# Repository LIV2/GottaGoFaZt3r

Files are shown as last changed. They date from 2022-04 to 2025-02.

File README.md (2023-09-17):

# GottaGoFaZt3r Fast RAM

256MB Autoconfig Fast RAM for the Amiga 3000/4000 

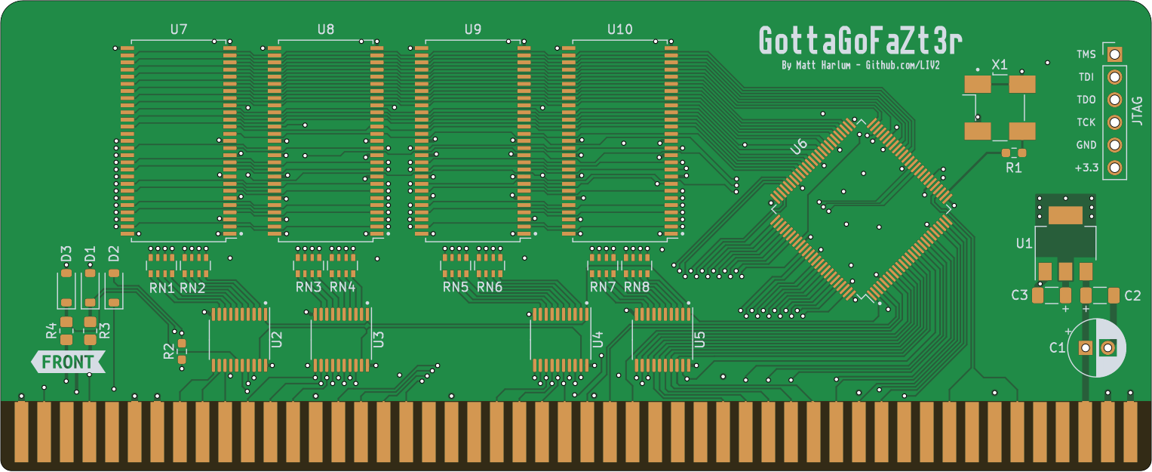
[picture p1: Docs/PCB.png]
PCB


## Table of contents
1. [Status](#status)
2. [Features](#features)
3. [Ordering PCBs](#ordering-pcbs)
4. [Bill of materials](#bill-of-materials)
5. [Troubleshooting](#troubleshooting)
6. [Special Thanks and Shoutouts](#special-thanks-and-shoutouts)
7. [License](#license)

## Status
Tested and working in the following configurations:
* Amiga 3000
* Amiga 4000 with A3640

## Features
128MB or 256MB Z3 Fast RAM  
Brand new 32Mx16 SDRAM chips are quite expensive so the board can also be fitted with 16Mx16 chips for a much lower build cost  

## Ordering PCBs
I recommend ordering from JLCPCB as this board was designed within their 4-layer specifications  
Recommended options when ordering:
* Thickness: 1.6mm
* Surface Finish: ENIG-RoHS
* Gold Fingers: Yes
* 45°finger chamfered: Yes

Layer sequence:
|Layer|File|
|-|-|
|L1|GottaGoFaSDZ3-F_Cu.gbr|
|L2|GottaGoFaSDZ3-In1_Cu.gbr|
|L3|GottaGoFaSDZ3-In2_Cu.gbr|
|L4|GottaGoFaSDZ3-B_Cu.gbr|

## Bill of materials

|Component|Location|QTY|Link|Notes|
|---|---|---|----|-----|
|0.1uF Ceramic Capacitor, 0603|C4-15,C17-44|40|[Mouser](https://www.mouser.com/ProductDetail/80-C603C104K5RAC3121)<br />[DigiKey](https://www.digikey.com/short/f7trtfwt)||
|10uF Ceramic Capacitor, 1206|C2-3,C16|3|[Mouser](https://www.mouser.com/ProductDetail/187-CL31A106MAHNNNE)<br />[DigiKey](https://www.digikey.com/short/rqt1br0q)||
|33 Ohm Resistor, 0603|R1|1|[Mouser](https://www.mouser.com/ProductDetail/603-RT0603DRE0733RL)<br />[DigiKey](https://www.digikey.com/short/40rdd4m1)||
|33 Ohm Resistor network, Convex 1206 (3.2x1.6mm)|RN1-8|8|[Mouser](https://www.mouser.com/ProductDetail/667-EXB-38V330JV)<br />[DigiKey](https://www.digikey.com/short/t08zh4pn)||
|10K Resistor, 0603|R2|1|[Mouser](https://www.mouser.com/ProductDetail/603-RT0603FRD0710KL)<br />[DigiKey](https://www.digikey.com/short/nvvrt5dw)||
|LM1117-3.3 SOT-223|U1|1|[Mouser](https://www.mouser.com/ProductDetail/926-LM1117IMP3.3NOPB)<br />[Digikey](https://www.digikey.se/short/jprv7r4q)||
|74LVC245N TSSOP|U2-5|4|[Mouser](https://www.mouser.com/ProductDetail/595-SN74LVC245APWT)<br />[DigiKey](https://www.digikey.se/short/vbmphn44)|Can be substituted with SN74LVTH245 or SN74LVCR2245|
|AS4C32M16SC 32Mx16 SDRAM, TSSOP-54|U7-10|4|[Mouser](https://www.mouser.com/ProductDetail/913-AS4C32M16SC-7TIN)<br />[DigiKey](https://www.digikey.com/short/wfwn8nmw)|Cheaper option is to use [A3V56S40GTP](https://www.mouser.com/ProductDetail/155-A3V56S40GTP-60) 16Mx16 for a 128MB configuration at a drastically lower price, or scavenge some 32Mx16 SDRAM from old SODIMMs*|
|Xilinx XC95144XL-10TQG100C 10ns 144 Macrocell CPLD|U6|1|[Mouser](https://www.mouser.com/ProductDetail/217-95144XL-10TQ100C)<br />[Digkey](https://www.digikey.com/short/w0r0j288)||
|Clock Oscillator, HCMOS, 7x5mm, 3.3V, ~66MHz|X1|1|[Mouser](https://www.mouser.com/ProductDetail/959-SM7745HEV-66.667)<br />[DigiKey](https://www.digikey.com/short/q8bzfwj4)|Anything close to 66MHz should work<br />Tested at 66.6666MHz|

__*__ I cannot provide technical support for RAM chips other than those explicitly listed in the BOM, others may work but you're on your own

## Troubleshooting
__Problem:__ The board is detected but there is less memory detected than there should be. or you see a message stating that the board is "Defective"  
__Resolution:__
1. Check all soldering looking for bad connections and shorts around the RAM and CPLD
2. Test the RAM using [ATK](https://github.com/keirf/amiga-stuff/releases)  
Look for the relevant region under "List and test regions" and test it  
Consult the memory layout to determine which IC is responsible for any stuck bits you might see

### Memory Layout
The memory is laid out in a way that causes it to wrap around above 128MB when only 128MB of ram is fitted to the card allowing either 128/256MB configuration with the same CPLD firmware.  
Kickstart will notice this wrap and add only 128MB to the free pool in this instance.

|Address|D0-15|D16-31|
|---|-----|---|
|40000000-43FFFFFF|U9|U7|
|44000000-47FFFFFF|U10|U8|
|48000000-4BFFFFFF|U9|U7|
|4C000000-4FFFFFFF|U10|U8|

## Special Thanks and Shoutouts
* [Niklas Ekström](https://github.com/niklasekstrom) for helping to clean up my messy code
* [GadgetUK164](https://www.youtube.com/gadgetuk164) for ~~being a guinea pig~~ beta testing many of my boards
* SparxUK also for being a helpful beta tester of many of my boards
* [CDH](https://github.com/cdhooper) and [Stefan Reinauer](https://github.com/reinauer) for helping me to get my A3000 going 
* [Rob "peepo" Taylor](https://tindie.com/stores/bobsbits/) whose A500++ got me started on my journey of tinkering with Amigas
* [jbilander](https://github.com/jbilander) who came up with the cool name :)
* RetroFletch
* [SukkoPera](https://github.com/SukkoPera)

## License

[][cc-by-sa]

This work is licensed under a
[Creative Commons Attribution-ShareAlike 4.0 International License][cc-by-sa].

[][cc-by-sa]

[cc-by-sa]: http://creativecommons.org/licenses/by-sa/4.0/
[cc-by-sa-image]: https://licensebuttons.net/l/by-sa/4.0/88x31.png
[cc-by-sa-shield]: https://img.shields.io/badge/License-CC%20BY--SA%204.0-lightgrey.svg

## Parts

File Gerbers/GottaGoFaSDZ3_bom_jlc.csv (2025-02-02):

Qty | Comment | Designator | Footprint | LCSC Part #
40 | 0.1uF | C4,C5,C6,C7,C8,C9,C10,C11,C12,C13,C14,C15,C17,C18,C19,C20,C21,C22,C23,C24,C25,C26,C27,C28,C29,C30,C31,C32,C33,C34,C35,C36,C37,C38,C39,C40,C41,C42,C43,C44 | C_0603_1608Metric_Pad1.08x0.95mm_HandSolder | C14663
3 | 10uF | C2,C3,C16 | C_1206_3216Metric_Pad1.33x1.80mm_HandSolder | C117023
1 | 47uF | C1 | CP_Radial_D6.3mm_P2.50mm | C239310
3 | BAT43W-V | D1,D2,D3 | D_SOD-123 | C7502694
1 | 33 | R1 | R_0603_1608Metric_Pad0.98x0.95mm_HandSolder | C23140
2 | 33 | R3,R4 | R_0805_2012Metric_Pad1.20x1.40mm_HandSolder | C23140
1 | 10K | R2 | R_0603_1608Metric_Pad0.98x0.95mm_HandSolder | C25804
8 | 33 | RN1,RN2,RN3,RN4,RN5,RN6,RN7,RN8 | R_Array_Convex_4x0603 | C25508
4 | 74LVCR2245 | U2,U3,U4,U5 | TSSOP-20_4.4x6.5mm_P0.65mm | C7848
4 | AS4C32M16SC | U7,U8,U9,U10 | TSOP-II-54_22.2x10.16mm_P0.8mm
1 | LM1117-3.3 | U1 | SOT-223-3_TabPin2 | C129334
1 | XC95144XL-TQ100 | U6 | TQFP-100_14x14mm_P0.5mm | C45126
1 | 66MHz | X1 | Oscillator_SMD_Abracon_ASV-4Pin_7.0x5.1mm_HandSoldering | C387152

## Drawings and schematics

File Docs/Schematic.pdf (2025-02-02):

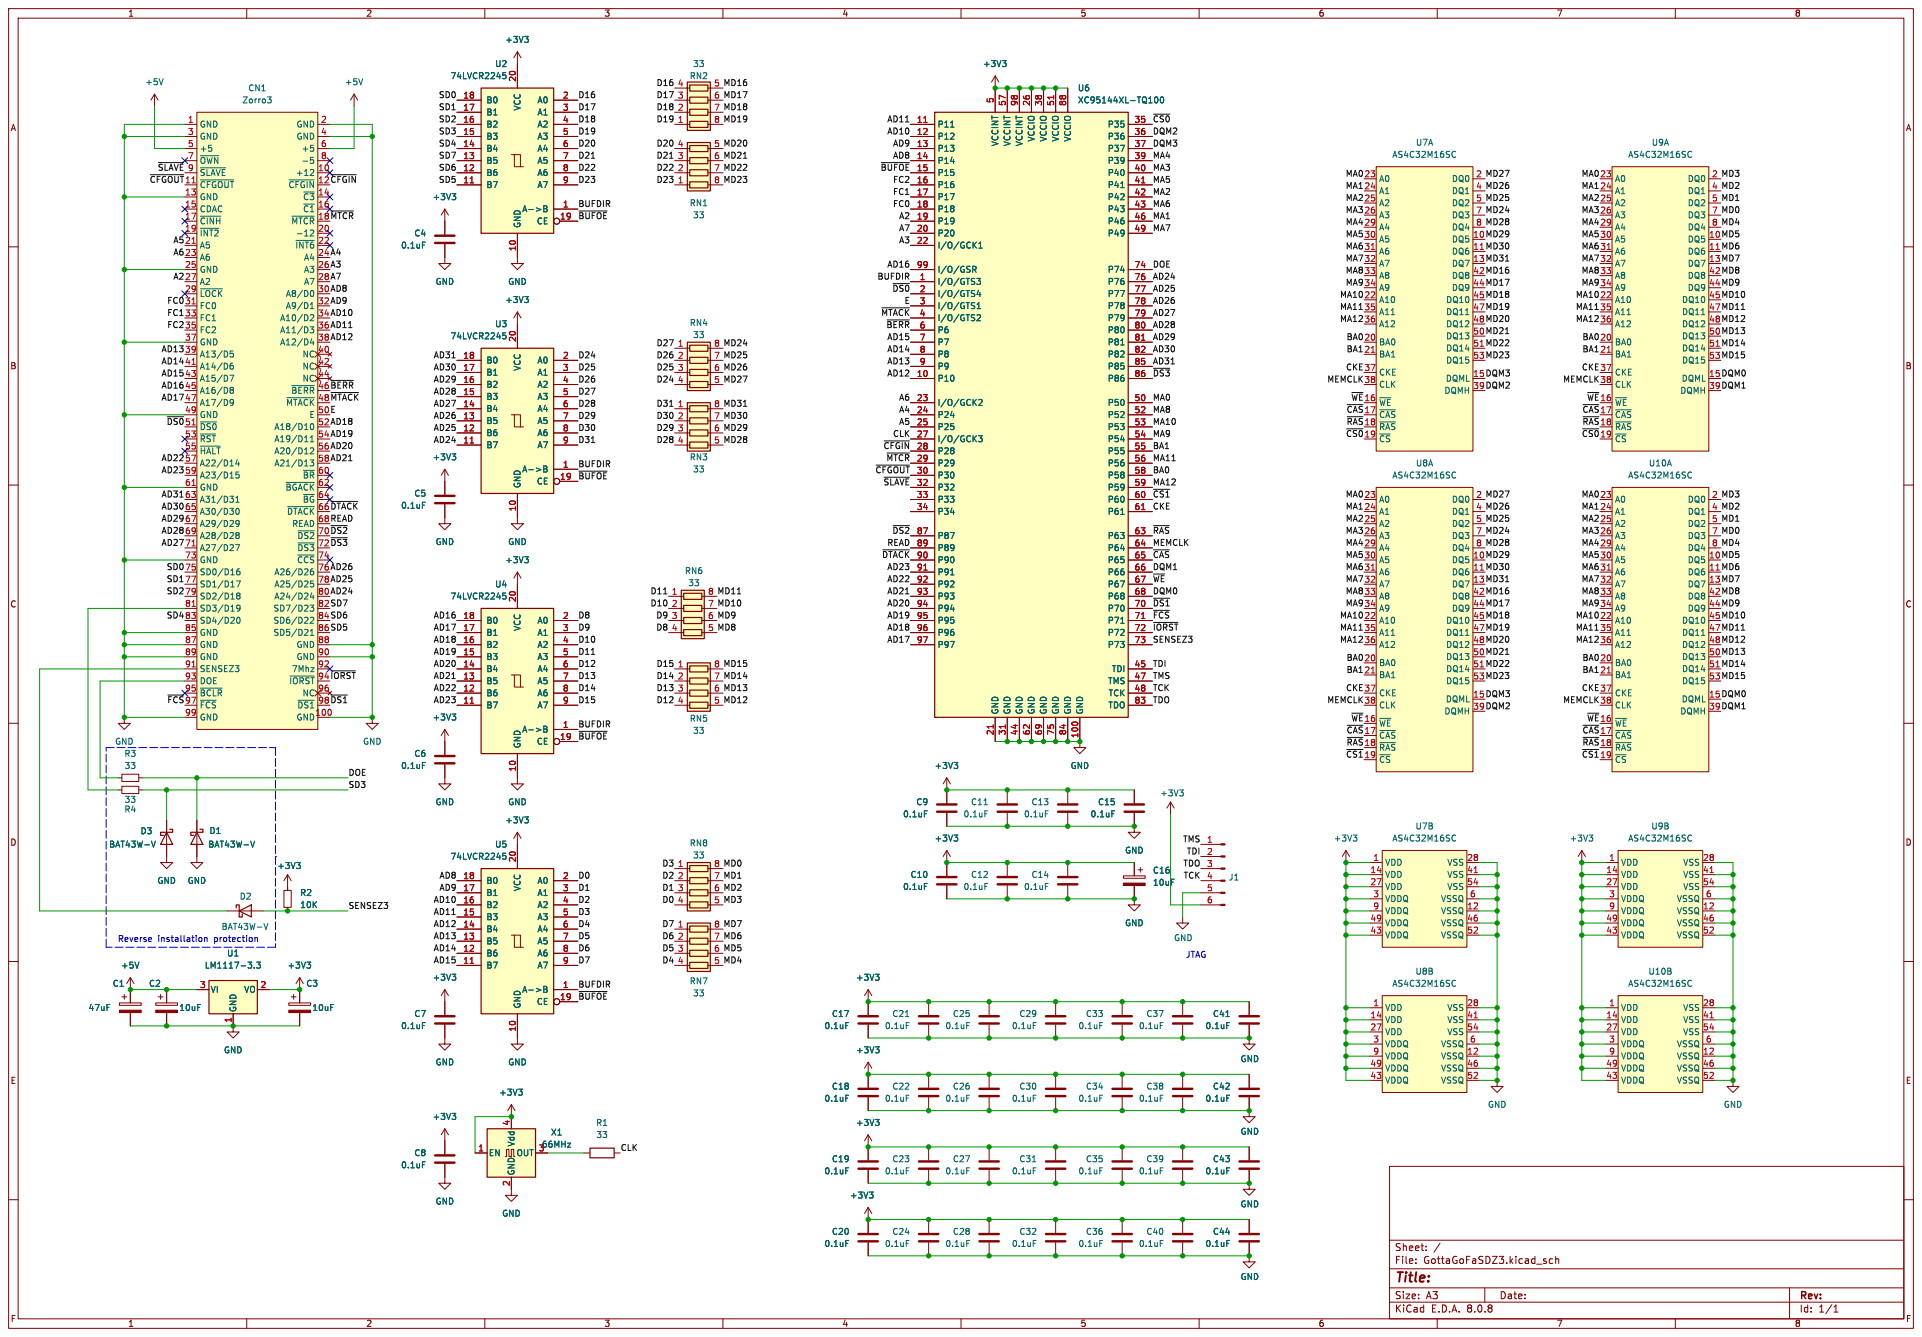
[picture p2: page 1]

Id: 1/1 Title: File: GottaGoFaSDZ3.kicad_sch Sheet: /

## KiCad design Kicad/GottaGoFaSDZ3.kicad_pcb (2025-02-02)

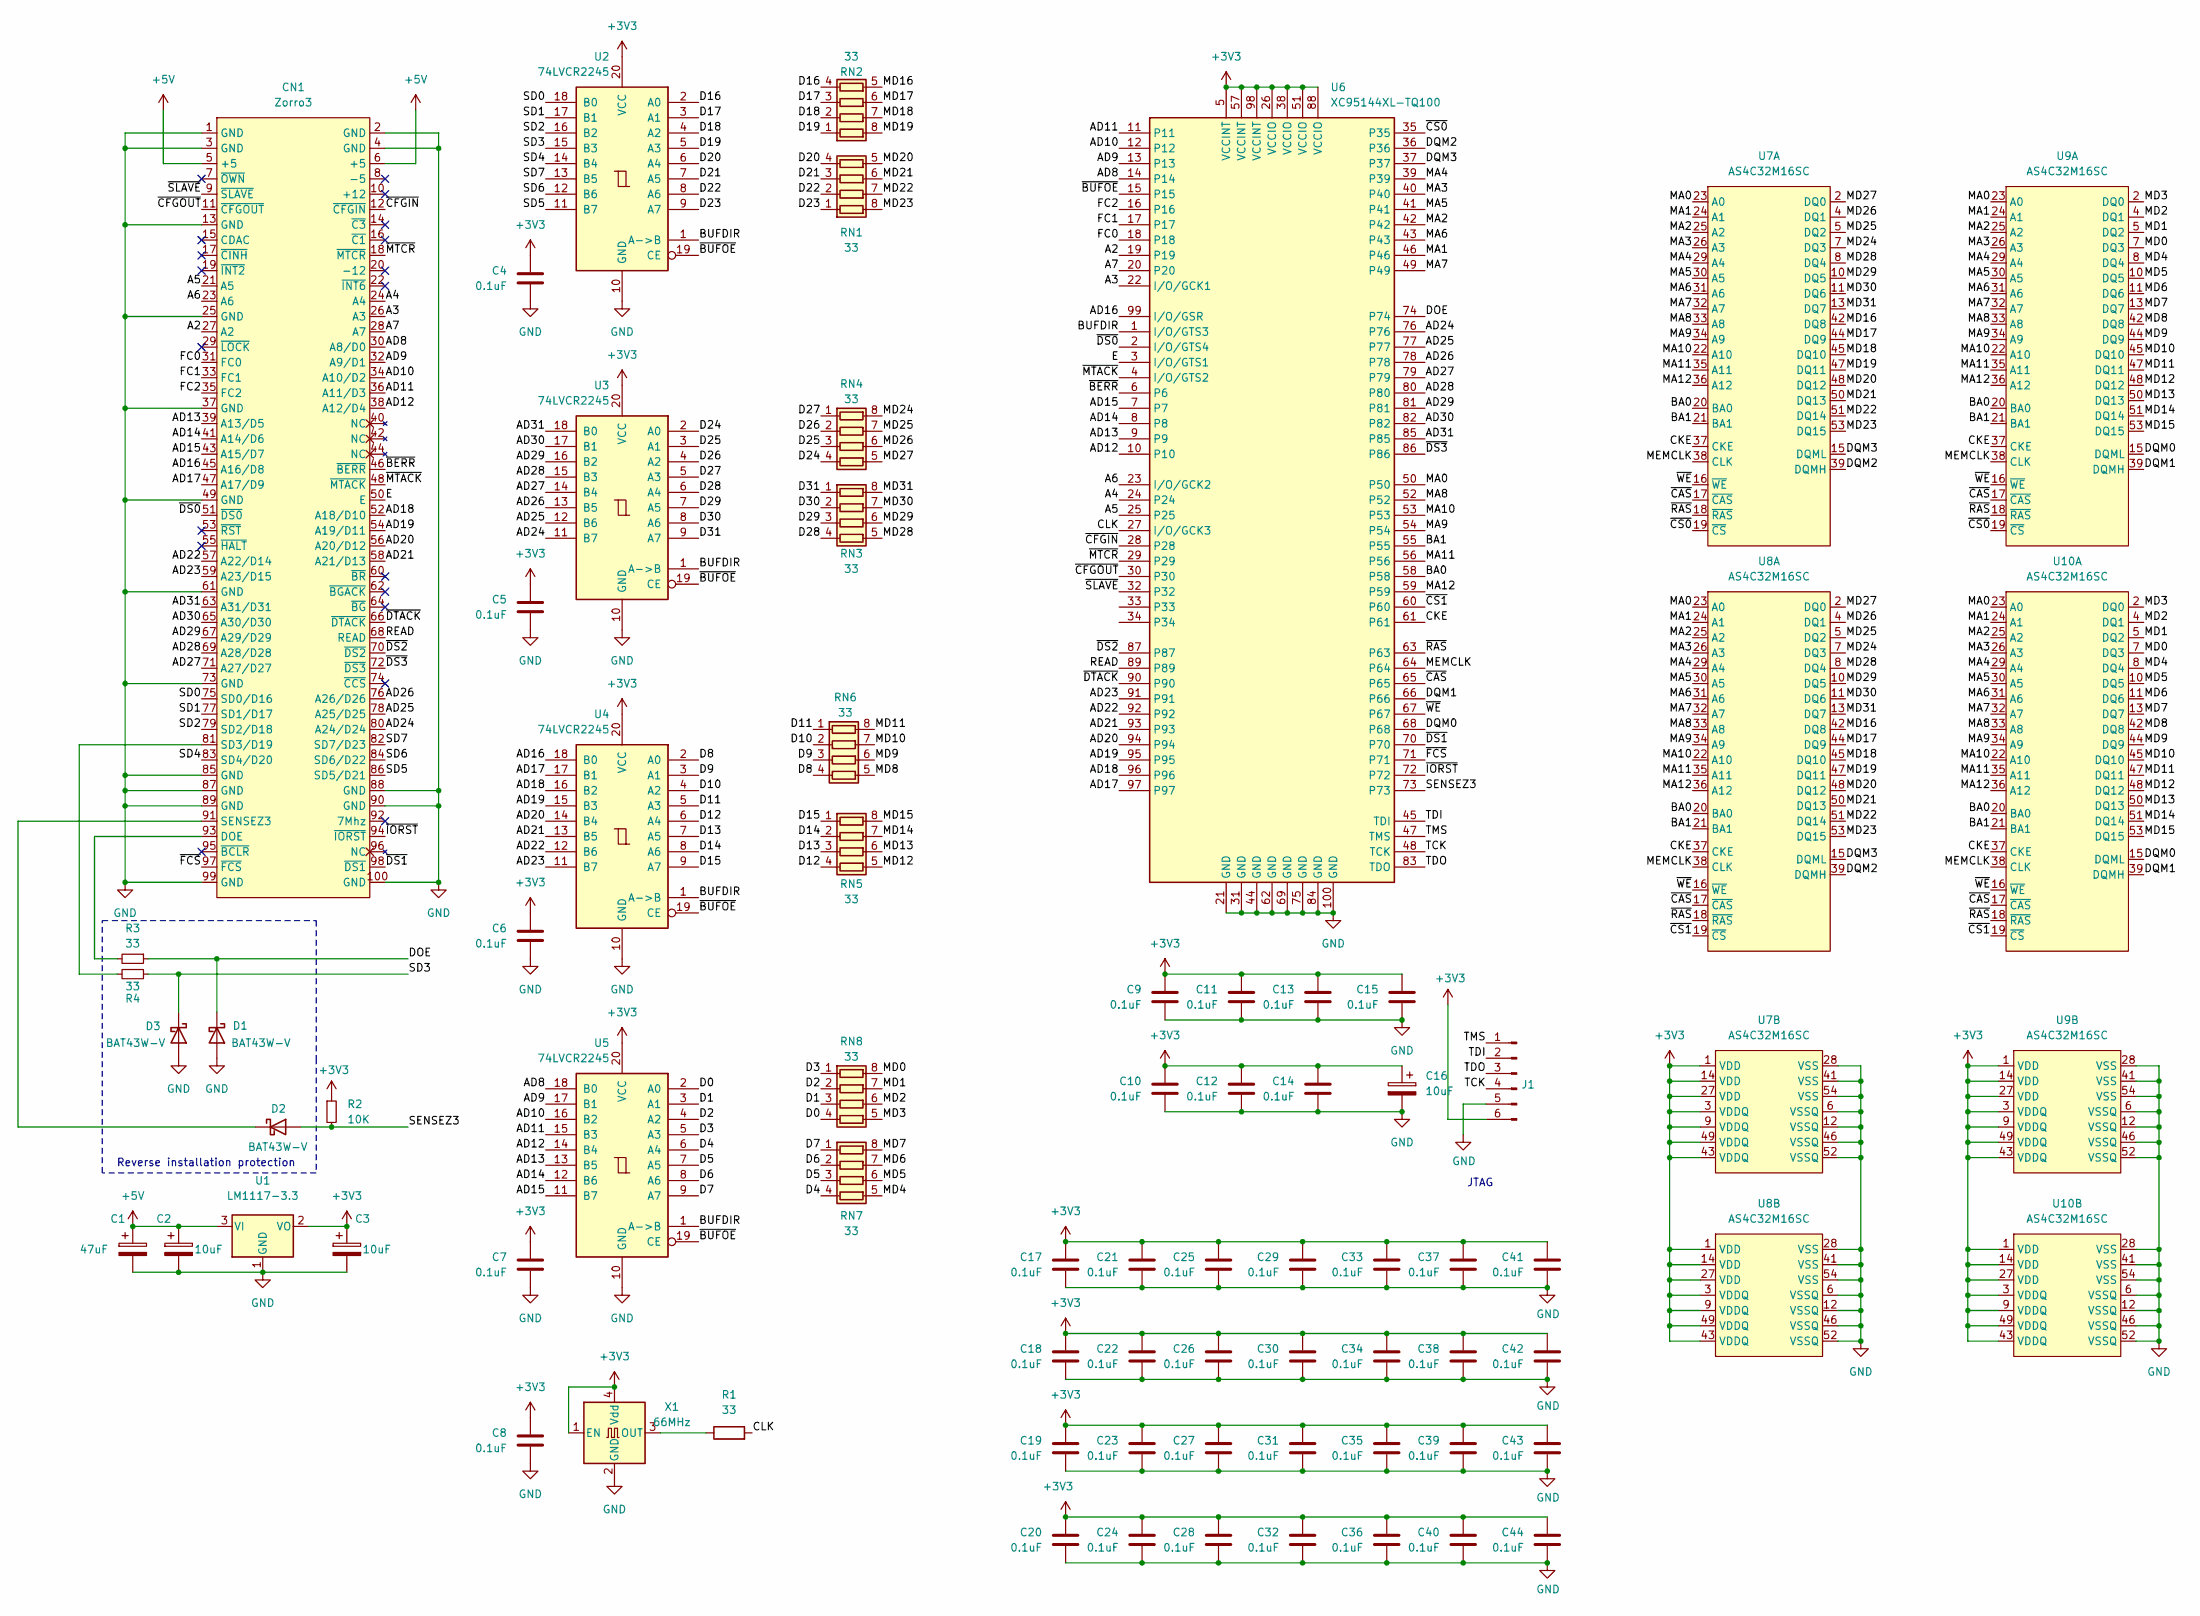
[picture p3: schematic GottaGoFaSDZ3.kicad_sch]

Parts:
C1: 47uF; CP_Radial_D6.3mm_P2.50mm; Mouser # 667-ECE-A1CKA101; LCSC # C239310
C2, C3, C16: 10uF; C_1206_3216Metric_Pad1.33x1.80mm_HandSolder; Mouser # 80-T491A106M020
C4: 0.1uF; C_0603_1608Metric_Pad1.08x0.95mm_HandSolder; Mouser # 80-C603C104K5RAC3121; LCSC # C14663
C5, C6, C7, C8, C9, C10, C11, C12, C13, C14, C15, C17, C18, C19, C20, C21, C22, C23, C24, C25, C26, C27, C28, C29, C30, C31, C32, C33, C34, C35, C36, C37, C38, C39, C40, C41, C42, C43, C44: 0.1uF; C_0603_1608Metric_Pad1.08x0.95mm_HandSolder; Mouser # 80-C603C104K5RAC3121
CN1: Zorro3
D1, D2, D3: BAT43W-V; D_SOD-123; Mouser # 78-BAT43W-G3-18; LCSC # C7502694
J1: Conn_01x06_Male; PinHeader_1x06_P2.54mm_Vertical
R1: 33; R_0603_1608Metric_Pad0.98x0.95mm_HandSolder; Mouser # 279-CRG0603F33R; LCSC # C23140
R2: 10K; R_0603_1608Metric_Pad0.98x0.95mm_HandSolder; Mouser # 279-CRGH0603J10K; LCSC # C25804
R3, R4: 33; R_0805_2012Metric_Pad1.20x1.40mm_HandSolder; Mouser # 279-CRG0603F33R; LCSC # C23140
RN1, RN2, RN3, RN4, RN5, RN6, RN7, RN8: 33; R_Array_Convex_4x0603; Mouser # 603-YC164-FR-0733RL; LCSC # C25508
U1: LM1117-3.3; SOT-223-3_TabPin2; Mouser # 926-LM1117IMP3.3NOPB
U2, U3, U4, U5: 74LVCR2245; TSSOP-20_4.4x6.5mm_P0.65mm; Mouser # 595-SN74LVC245APWT
U6: XC95144XL-TQ100; TQFP-100_14x14mm_P0.5mm; Mouser # 217-5144XL-10TQG100C; LCSC # C45126
U7, U8, U9, U10: AS4C32M16SC; TSOP-II-54_22.2x10.16mm_P0.8mm
X1: 66MHz; Oscillator_SMD_Abracon_ASV-4Pin_7.0x5.1mm_HandSoldering; Mouser # 959-SM7745HEV-66.667; LCSC # C387152

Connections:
+3V3: C3.1, C4.1, C5.1, C6.1, C7.1, C8.1, C9.1, C10.1, C11.1, C12.1, C13.1, C14.1, C15.1, C16.1, C17.1, C18.1, C19.1, C20.1, C21.1, C22.1, C23.1, C24.1, C25.1, C26.1, C27.1, C28.1, C29.1, C30.1, C31.1, C32.1, C33.1, C34.1, C35.1, C36.1, C37.1, C38.1, C39.1, C40.1, C41.1, C42.1, C43.1, C44.1, J1.6, R2.1, U1.2 (VO), U2.20 (VCC), U3.20 (VCC), U4.20 (VCC), U5.20 (VCC), U6.5 (VCCINT), U6.26 (VCCIO), U6.38 (VCCIO), U6.51 (VCCIO), U6.57 (VCCINT), U6.88 (VCCIO), U6.98 (VCCINT), U7.1 (VDD), U7.3 (VDDQ), U7.9 (VDDQ), U7.14 (VDD), U7.27 (VDD), U7.43 (VDDQ), U7.49 (VDDQ), U8.1 (VDD), U8.3 (VDDQ), U8.9 (VDDQ), U8.14 (VDD), U8.27 (VDD), U8.43 (VDDQ), U8.49 (VDDQ), U9.1 (VDD), U9.3 (VDDQ), U9.9 (VDDQ), U9.14 (VDD), U9.27 (VDD), U9.43 (VDDQ), U9.49 (VDDQ), U10.1 (VDD), U10.3 (VDDQ), U10.9 (VDDQ), U10.14 (VDD), U10.27 (VDD), U10.43 (VDDQ), U10.49 (VDDQ), X1.1 (EN), X1.4 (Vdd)
+5V: C1.1, C2.1, CN1.5 (+5), CN1.6 (+5), U1.3 (VI)
/A2: CN1.27 (A2), U6.19
/A3: CN1.26 (A3), U6.22 (I/O/GCK1)
/A4: CN1.24 (A4), U6.24
/A5: CN1.21 (A5), U6.25
/A6: CN1.23 (A6), U6.23 (I/O/GCK2)
/A7: CN1.28 (A7), U6.20
/AD8: CN1.30 (A8/D0), U5.18 (B0), U6.14
/AD9: CN1.32 (A9/D1), U5.17 (B1), U6.13
/AD10: CN1.34 (A10/D2), U5.16 (B2), U6.12
/AD11: CN1.36 (A11/D3), U5.15 (B3), U6.11
/AD12: CN1.38 (A12/D4), U5.14 (B4), U6.10
/AD13: CN1.39 (A13/D5), U5.13 (B5), U6.9
/AD14: CN1.41 (A14/D6), U5.12 (B6), U6.8
/AD15: CN1.43 (A15/D7), U5.11 (B7), U6.7
/AD16: CN1.45 (A16/D8), U4.18 (B0), U6.99 (I/O/GSR)
/AD17: CN1.47 (A17/D9), U4.17 (B1), U6.97
/AD18: CN1.52 (A18/D10), U4.16 (B2), U6.96
/AD19: CN1.54 (A19/D11), U4.15 (B3), U6.95
/AD20: CN1.56 (A20/D12), U4.14 (B4), U6.94
/AD21: CN1.58 (A21/D13), U4.13 (B5), U6.93
/AD22: CN1.57 (A22/D14), U4.12 (B6), U6.92
/AD23: CN1.59 (A23/D15), U4.11 (B7), U6.91
/AD24: CN1.80 (A24/D24), U3.11 (B7), U6.76
/AD25: CN1.78 (A25/D25), U3.12 (B6), U6.77
/AD26: CN1.76 (A26/D26), U3.13 (B5), U6.78
/AD27: CN1.71 (A27/D27), U3.14 (B4), U6.79
/AD28: CN1.69 (A28/D28), U3.15 (B3), U6.80
/AD29: CN1.67 (A29/D29), U3.16 (B2), U6.81
/AD30: CN1.65 (A30/D30), U3.17 (B1), U6.82
/AD31: CN1.63 (A31/D31), U3.18 (B0), U6.85
/BA0: U6.58, U7.20 (BA0), U8.20 (BA0), U9.20 (BA0), U10.20 (BA0)
/BA1: U6.55, U7.21 (BA1), U8.21 (BA1), U9.21 (BA1), U10.21 (BA1)
/BUFDIR: U2.1 (A->B), U3.1 (A->B), U4.1 (A->B), U5.1 (A->B), U6.1 (I/O/GTS3)
/CKE: U6.61, U7.37 (CKE), U8.37 (CKE), U9.37 (CKE), U10.37 (CKE)
/CLK: R1.2, U6.27 (I/O/GCK3)
/D0: RN8.4 (R4.1), U5.2 (A0)
/D1: RN8.3 (R3.1), U5.3 (A1)
/D2: RN8.2 (R2.1), U5.4 (A2)
/D3: RN8.1 (R1.1), U5.5 (A3)
/D4: RN7.4 (R4.1), U5.6 (A4)
/D5: RN7.3 (R3.1), U5.7 (A5)
/D6: RN7.2 (R2.1), U5.8 (A6)
/D7: RN7.1 (R1.1), U5.9 (A7)
/D8: RN6.4 (R4.1), U4.2 (A0)
/D9: RN6.3 (R3.1), U4.3 (A1)
/D10: RN6.2 (R2.1), U4.4 (A2)
/D11: RN6.1 (R1.1), U4.5 (A3)
/D12: RN5.4 (R4.1), U4.6 (A4)
/D13: RN5.3 (R3.1), U4.7 (A5)
/D14: RN5.2 (R2.1), U4.8 (A6)
/D15: RN5.1 (R1.1), U4.9 (A7)
/D16: RN2.4 (R4.1), U2.2 (A0)
/D17: RN2.3 (R3.1), U2.3 (A1)
/D18: RN2.2 (R2.1), U2.4 (A2)
/D19: RN2.1 (R1.1), U2.5 (A3)
/D20: RN1.4 (R4.1), U2.6 (A4)
/D21: RN1.3 (R3.1), U2.7 (A5)
/D22: RN1.2 (R2.1), U2.8 (A6)
/D23: RN1.1 (R1.1), U2.9 (A7)
/D24: RN4.4 (R4.1), U3.2 (A0)
/D25: RN4.3 (R3.1), U3.3 (A1)
/D26: RN4.2 (R2.1), U3.4 (A2)
/D27: RN4.1 (R1.1), U3.5 (A3)
/D28: RN3.4 (R4.1), U3.6 (A4)
/D29: RN3.3 (R3.1), U3.7 (A5)
/D30: RN3.2 (R2.1), U3.8 (A6)
/D31: RN3.1 (R1.1), U3.9 (A7)
/DOE: D1.1 (K), R3.1, U6.74
/DQM0: U6.68, U9.15 (DQML), U10.15 (DQML)
/DQM1: U6.66, U9.39 (DQMH), U10.39 (DQMH)
/DQM2: U6.36, U7.39 (DQMH), U8.39 (DQMH)
/DQM3: U6.37, U7.15 (DQML), U8.15 (DQML)
/E: CN1.50 (E), U6.3 (I/O/GTS1)
/FC0: CN1.31 (FC0), U6.18
/FC1: CN1.33 (FC1), U6.17
/FC2: CN1.35 (FC2), U6.16
/MA0: U6.50, U7.23 (A0), U8.23 (A0), U9.23 (A0), U10.23 (A0)
/MA1: U6.46, U7.24 (A1), U8.24 (A1), U9.24 (A1), U10.24 (A1)
/MA2: U6.42, U7.25 (A2), U8.25 (A2), U9.25 (A2), U10.25 (A2)
/MA3: U6.40, U7.26 (A3), U8.26 (A3), U9.26 (A3), U10.26 (A3)
/MA4: U6.39, U7.29 (A4), U8.29 (A4), U9.29 (A4), U10.29 (A4)
/MA5: U6.41, U7.30 (A5), U8.30 (A5), U9.30 (A5), U10.30 (A5)
/MA6: U6.43, U7.31 (A6), U8.31 (A6), U9.31 (A6), U10.31 (A6)
/MA7: U6.49, U7.32 (A7), U8.32 (A7), U9.32 (A7), U10.32 (A7)
/MA8: U6.52, U7.33 (A8), U8.33 (A8), U9.33 (A8), U10.33 (A8)
/MA9: U6.54, U7.34 (A9), U8.34 (A9), U9.34 (A9), U10.34 (A9)
/MA10: U6.53, U7.22 (A10), U8.22 (A10), U9.22 (A10), U10.22 (A10)
/MA11: U6.56, U7.35 (A11), U8.35 (A11), U9.35 (A11), U10.35 (A11)
/MA12: U6.59, U7.36 (A12), U8.36 (A12), U9.36 (A12), U10.36 (A12)
/MD0: RN8.8 (R1.2), U9.7 (DQ3), U10.7 (DQ3)
/MD1: RN8.7 (R2.2), U9.5 (DQ2), U10.5 (DQ2)
/MD2: RN8.6 (R3.2), U9.4 (DQ1), U10.4 (DQ1)
/MD3: RN8.5 (R4.2), U9.2 (DQ0), U10.2 (DQ0)
/MD4: RN7.5 (R4.2), U9.8 (DQ4), U10.8 (DQ4)
/MD5: RN7.6 (R3.2), U9.10 (DQ5), U10.10 (DQ5)
/MD6: RN7.7 (R2.2), U9.11 (DQ6), U10.11 (DQ6)
/MD7: RN7.8 (R1.2), U9.13 (DQ7), U10.13 (DQ7)
/MD8: RN6.5 (R4.2), U9.42 (DQ8), U10.42 (DQ8)
/MD9: RN6.6 (R3.2), U9.44 (DQ9), U10.44 (DQ9)
/MD10: RN6.7 (R2.2), U9.45 (DQ10), U10.45 (DQ10)
/MD11: RN6.8 (R1.2), U9.47 (DQ11), U10.47 (DQ11)
/MD12: RN5.5 (R4.2), U9.48 (DQ12), U10.48 (DQ12)
/MD13: RN5.6 (R3.2), U9.50 (DQ13), U10.50 (DQ13)
/MD14: RN5.7 (R2.2), U9.51 (DQ14), U10.51 (DQ14)
/MD15: RN5.8 (R1.2), U9.53 (DQ15), U10.53 (DQ15)
/MD16: RN2.5 (R4.2), U7.42 (DQ8), U8.42 (DQ8)
/MD17: RN2.6 (R3.2), U7.44 (DQ9), U8.44 (DQ9)
/MD18: RN2.7 (R2.2), U7.45 (DQ10), U8.45 (DQ10)
/MD19: RN2.8 (R1.2), U7.47 (DQ11), U8.47 (DQ11)
/MD20: RN1.5 (R4.2), U7.48 (DQ12), U8.48 (DQ12)
/MD21: RN1.6 (R3.2), U7.50 (DQ13), U8.50 (DQ13)
/MD22: RN1.7 (R2.2), U7.51 (DQ14), U8.51 (DQ14)
/MD23: RN1.8 (R1.2), U7.53 (DQ15), U8.53 (DQ15)
/MD24: RN4.8 (R1.2), U7.7 (DQ3), U8.7 (DQ3)
/MD25: RN4.7 (R2.2), U7.5 (DQ2), U8.5 (DQ2)
/MD26: RN4.6 (R3.2), U7.4 (DQ1), U8.4 (DQ1)
/MD27: RN4.5 (R4.2), U7.2 (DQ0), U8.2 (DQ0)
/MD28: RN3.5 (R4.2), U7.8 (DQ4), U8.8 (DQ4)
/MD29: RN3.6 (R3.2), U7.10 (DQ5), U8.10 (DQ5)
/MD30: RN3.7 (R2.2), U7.11 (DQ6), U8.11 (DQ6)
/MD31: RN3.8 (R1.2), U7.13 (DQ7), U8.13 (DQ7)
/MEMCLK: U6.64, U7.38 (CLK), U8.38 (CLK), U9.38 (CLK), U10.38 (CLK)
/READ: CN1.68 (READ), U6.89
/SD0: CN1.75 (SD0/D16), U2.18 (B0)
/SD1: CN1.77 (SD1/D17), U2.17 (B1)
/SD2: CN1.79 (SD2/D18), U2.16 (B2)
/SD3: D3.1 (K), R4.1, U2.15 (B3)
/SD4: CN1.83 (SD4/D20), U2.14 (B4)
/SD5: CN1.86 (SD5/D21), U2.11 (B7)
/SD6: CN1.84 (SD6/D22), U2.12 (B6)
/SD7: CN1.82 (SD7/D23), U2.13 (B5)
/SENSEZ3: D2.2 (A), R2.2, U6.73
/TCK: J1.4, U6.48 (TCK)
/TDI: J1.2, U6.45 (TDI)
/TDO: J1.3, U6.83 (TDO)
/TMS: J1.1, U6.47 (TMS)
/~BERR: CN1.46 (~BERR), U6.6
/~BUFOE: U2.19 (CE), U3.19 (CE), U4.19 (CE), U5.19 (CE), U6.15
/~CAS: U6.65, U7.17 (~CAS), U8.17 (~CAS), U9.17 (~CAS), U10.17 (~CAS)
/~CFGIN: CN1.12 (~CFGIN), U6.28
/~CFGOUT: CN1.11 (~CFGOUT), U6.30
/~CS0: U6.35, U7.19 (~CS), U9.19 (~CS)
/~CS1: U6.60, U8.19 (~CS), U10.19 (~CS)
/~DS0: CN1.51 (~DS0), U6.2 (I/O/GTS4)
/~DS1: CN1.98 (~DS1), U6.70
/~DS2: CN1.70 (~DS2), U6.87
/~DS3: CN1.72 (~DS3), U6.86
/~DTACK: CN1.66 (~DTACK), U6.90
/~FCS: CN1.97 (~FCS), U6.71
/~IORST: CN1.94 (~IORST), U6.72
/~MTACK: CN1.48 (~MTACK), U6.4 (I/O/GTS2)
/~MTCR: CN1.18 (~MTCR), U6.29
/~RAS: U6.63, U7.18 (~RAS), U8.18 (~RAS), U9.18 (~RAS), U10.18 (~RAS)
/~SLAVE: CN1.9 (~SLAVE), U6.32
/~WE: U6.67, U7.16 (~WE), U8.16 (~WE), U9.16 (~WE), U10.16 (~WE)
GND: C1.2, C2.2, C3.2, C4.2, C5.2, C6.2, C7.2, C8.2, C9.2, C10.2, C11.2, C12.2, C13.2, C14.2, C15.2, C16.2, C17.2, C18.2, C19.2, C20.2, C21.2, C22.2, C23.2, C24.2, C25.2, C26.2, C27.2, C28.2, C29.2, C30.2, C31.2, C32.2, C33.2, C34.2, C35.2, C36.2, C37.2, C38.2, C39.2, C40.2, C41.2, C42.2, C43.2, C44.2, CN1.1 (GND), CN1.2 (GND), CN1.3 (GND), CN1.4 (GND), CN1.13 (GND), CN1.25 (GND), CN1.37 (GND), CN1.49 (GND), CN1.61 (GND), CN1.73 (GND), CN1.85 (GND), CN1.87 (GND), CN1.88 (GND), CN1.89 (GND), CN1.90 (GND), CN1.99 (GND), CN1.100 (GND), D1.2 (A), D3.2 (A), J1.5, U1.1 (GND), U2.10 (GND), U3.10 (GND), U4.10 (GND), U5.10 (GND), U6.21 (GND), U6.31 (GND), U6.44 (GND), U6.62 (GND), U6.69 (GND), U6.75 (GND), U6.84 (GND), U6.100 (GND), U7.6 (VSSQ), U7.12 (VSSQ), U7.28 (VSS), U7.41 (VSS), U7.46 (VSSQ), U7.52 (VSSQ), U7.54 (VSS), U8.6 (VSSQ), U8.12 (VSSQ), U8.28 (VSS), U8.41 (VSS), U8.46 (VSSQ), U8.52 (VSSQ), U8.54 (VSS), U9.6 (VSSQ), U9.12 (VSSQ), U9.28 (VSS), U9.41 (VSS), U9.46 (VSSQ), U9.52 (VSSQ), U9.54 (VSS), U10.6 (VSSQ), U10.12 (VSSQ), U10.28 (VSS), U10.41 (VSS), U10.46 (VSSQ), U10.52 (VSSQ), U10.54 (VSS), X1.2 (GND)
unnamed: CN1.93 (DOE), R3.2
unnamed: CN1.81 (SD3/D19), R4.2
unnamed: CN1.91 (SENSEZ3), D2.1 (K)
unnamed: R1.1, X1.3 (OUT)

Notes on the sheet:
JTAG
Reverse installation protection

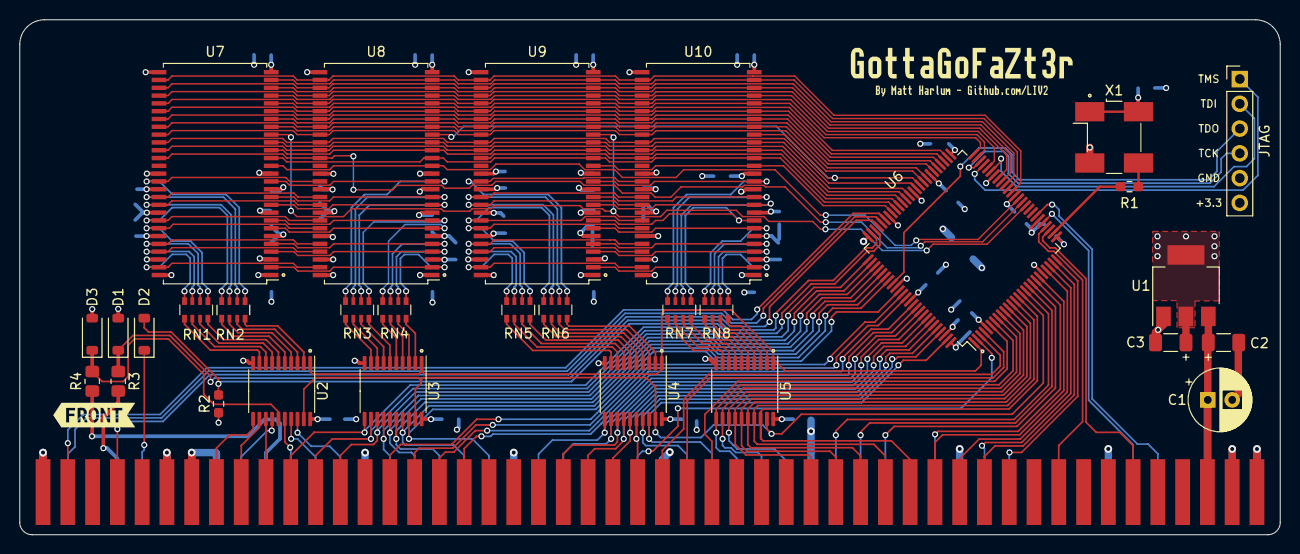
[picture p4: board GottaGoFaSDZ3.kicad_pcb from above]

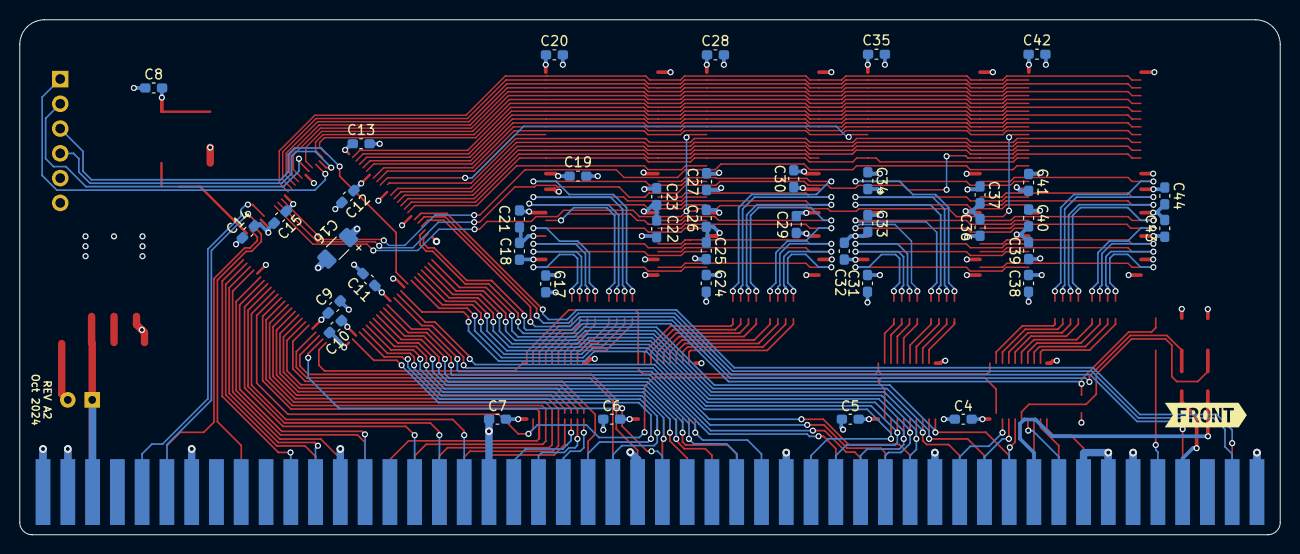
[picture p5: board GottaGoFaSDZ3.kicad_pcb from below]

Board: 4 copper layers, 129.2 x 52.8 mm, 76 parts (42 on the bottom side), 162 nets.

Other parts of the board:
kibuzzard-621BB44F: G***; kibuzzard-621BB44F
kibuzzard-621BB463: G***; kibuzzard-621BB463
kibuzzard-622DC477: G***; kibuzzard-622DC477
kibuzzard-622DC493: G***; kibuzzard-622DC493

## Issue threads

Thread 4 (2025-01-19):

Blinking yellow screen when GGFZ3 installed together with a CyberVision 64 card.

hishamk, 2025-01-19:
The culprit seems that somehow it's incompatible with the CyberVision 64. It only works with the CV64 (Rev 2.0.1) removed. The GGFZ3 works fine with other cards installed such as an X-Surf 100.

Specs: Amiga 3000 Stock '030@25MHz / 16MB + CV64 + X-Surf 100.

I can reprogram the CPLD if a new firmware version comes out or help debug it.

LIV2, 2025-01-19:
Hi,

I don't have a Cybervision 64 to test with myself but I have asked around for people who can also test this combination.
I've had one report that it works for them however I'm still waiting to hear more.

In the meantime, could you please try swapping the cards around so they're installed in a different order?

hishamk, 2025-01-19:
I tried several combinations of swapping the cards around to no avail. As long as the CV64 is in one of the slots, it doesn't work.

LIV2, 2025-01-20:
Ok can I please get the following info to help me investigate further?

* Kickstart version
* Buster revision
* Stock A3000 daughterboard? If not, which one is installed?

hishamk, 2025-01-24:
Sorry, was a bit late to look up this info:

Kickstart - 3.1.4 ROMs installed
Buster rev 11 (upgraded from 9)
A3000 motherboard rev 09/03
A3000 daughterboard rev 07/01 (upgraded from rev 5, which I still have but not installed).

LIV2, 2025-01-24:
Great thanks for that info

Attached is a zip file containing two debug firmwares.

Can you please flash debug-1.jed and let me know if you still get a yellow screen?
This will prevent the memory from being added to the system memory lists but will allow for doing memory tests with ATK etc
If the system boots, check the early startup menu to see the board address then do a manual memory test in ATK
If the ram board is the first Z3 card in the list it should be assigned an address range of 40000000-4FFFFFFF please perform a memory test on it

If you still get a yellow screen, please flash debug-2 - this will prevent the memory from being enabled at all but will help me determine what is causing the yellow screen.

[ggfz3-debugfw.zip](https://github.com/user-attachments/files/18533762/ggfz3-debugfw.zip)

hishamk, 2025-01-24:
Thanks, will report back once I do that.

hishamk, 2025-03-05:
Unfortunately both debug-1 and debug-2 result in a yellow screen / no boot.

LIV2, 2025-03-11:
@hishamk since you still get a yellow screen with debug-2 this implies some hardware issue rather than a firmware one

The most obvious cause of that yellow screen in this case would be if the slave signal was shorted to ground.
The Slave signal is highlighted here in red, please check that there is not a solder bridge at the CPLD shorting it and check that it is not shorted to ground with a multimeter

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

If you don't find any issue there, carefully inspect the soldering of the CPLD and buffer ics.

Also if possible boot diagrom and run the automated autoconfig item and let me know if that works or if it throws a bus error

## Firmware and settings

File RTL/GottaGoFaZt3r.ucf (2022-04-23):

NET "A<2>"    LOC = "P19"  ; 
NET "A<3>"    LOC = "P22"  ; 
NET "A<4>"    LOC = "P24"  ; 
NET "A<5>"    LOC = "P25"  ; 
NET "A<6>"    LOC = "P23"  ; 
NET "A<7>"    LOC = "P20"  ; 
NET "A<10>"  LOC = "P12"  ; 
NET "A<11>"  LOC = "P11"  ; 
NET "A<12>"  LOC = "P10"  ; 
NET "A<13>"  LOC = "P9"  ; 
NET "A<14>"  LOC = "P8"  ; 
NET "A<15>"  LOC = "P7"  ; 
NET "A<16>"  LOC = "P99"  ; 
NET "A<17>"  LOC = "P97"  ; 
NET "A<18>"  LOC = "P96"  ; 
NET "A<19>"  LOC = "P95"  ; 
NET "A<20>"  LOC = "P94"  ; 
NET "A<21>"  LOC = "P93"  ; 
NET "A<22>"  LOC = "P92"  ; 
NET "A<23>"  LOC = "P91"  ; 
NET "A<24>"  LOC = "P76"  ; 
NET "A<25>"  LOC = "P77"  ; 
NET "A<26>"  LOC = "P78"  ; 
NET "A<27>"  LOC = "P79"  ; 
NET "AD<28>"  LOC = "P80"  ; 
NET "AD<29>"  LOC = "P81"  ; 
NET "AD<30>"  LOC = "P82"  ; 
NET "AD<31>"  LOC = "P85"  ; 
NET "A<8>"   LOC = "P14"  ; 
NET "A<9>"   LOC = "P13"  ; 
NET "BA<0>"   LOC = "P58"  ; 
NET "BA<1>"   LOC = "P55"  ; 
NET "BERR_n"   LOC = "P6"  ; 
NET "BUFDIR"  LOC = "P1"  ; 
NET "BUFOE_n"  LOC = "P15"  ; 
NET "CAS_n"    LOC = "P65"  ; 
NET "CFGIN_n"  LOC = "P28"  ; 
NET "CFGOUT_n" LOC = "P30"  ; 
NET "CKE"     LOC = "P61"  ; 
NET "CLK"     LOC = "P27"  ; 
NET "CLK"     BUFG = "CLK" ; 
NET "CS_n<0>"   LOC = "P35"  ; 
NET "CS_n<1>"   LOC = "P60"  ; 
NET "DOE"     LOC = "P74"  ; 
NET "DQM_n<0>"  LOC = "P68"  ; 
NET "DQM_n<1>"  LOC = "P66"  ; 
NET "DQM_n<2>"  LOC = "P36"  ; 
NET "DQM_n<3>"  LOC = "P37"  ; 
NET "DS_n<0>"    LOC = "P2"  ; 
NET "DS_n<1>"    LOC = "P70"  ; 
NET "DS_n<2>"    LOC = "P87"  ; 
NET "DS_n<3>"    LOC = "P86"  ; 
NET "DTACK_n"  LOC = "P90"  ; 
NET "E"       LOC = "P3"  ; 
NET "FC<0>"   LOC = "P18"  ; 
NET "FC<1>"   LOC = "P17"  ; 
NET "FC<2>"   LOC = "P16"  ; 
NET "FCS_n"    LOC = "P71"  ; 
NET "MA<0>"   LOC = "P50"  ; 
NET "MA<1>"   LOC = "P46"  ; 
NET "MA<10>"  LOC = "P53"  ; 
NET "MA<11>"  LOC = "P56"  ; 
NET "MA<12>"  LOC = "P59"  ; 
NET "MA<2>"   LOC = "P42"  ; 
NET "MA<3>"   LOC = "P40"  ; 
NET "MA<4>"   LOC = "P39"  ; 
NET "MA<5>"   LOC = "P41"  ; 
NET "MA<6>"   LOC = "P43"  ; 
NET "MA<7>"   LOC = "P49"  ; 
NET "MA<8>"   LOC = "P52"  ; 
NET "MA<9>"   LOC = "P54"  ; 
NET "MEMCLK"  LOC = "P64"  ; 
NET "MTACK_n"  LOC = "P4"  ; 
NET "MTCR_n"   LOC = "P29"  ; 
NET "RAS_n"    LOC = "P63"  ; 
NET "READ"    LOC = "P89"  ; 
NET "RST_n"    LOC = "P72"  ; 
NET "SENSEZ3" LOC = "P73"  ; 
NET "SLAVE_n"  LOC = "P32"  ; 
NET "TP1"     LOC = "P34"  ; 
NET "TP2"     LOC = "P33"  ; 
NET "WE_n"     LOC = "P67"  ;

NET "CLK" TNM_NET = CLK;
TIMESPEC TS_CLK = PERIOD "CLK" 66 MHz HIGH 50%;

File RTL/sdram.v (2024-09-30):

/*
GottaGoFaZt3r
Copyright 2022 Matthew Harlum

GottaGoFaZt3r is licensed under a
Creative Commons Attribution-ShareAlike 4.0 International License.

You should have received a copy of the license along with this
work. If not, see <http://creativecommons.org/licenses/by-sa/4.0/>.
*/
`timescale 1ns / 1ps

module SDRAM(
    input [27:2] ADDR,
    input [3:0] DS_n,
    input ram_cycle,
    input RESET_n,
    input RW,
    input CLK,
    input ECLK,
    input configured,
    input [1:0] z3_state,
    output reg [1:0] BA,
    output reg [12:0] MADDR,
    output reg CAS_n,
    output reg RAS_n,
    output reg [1:0] CS_n,
    output reg WE_n,
    output reg CKE,
    output reg [3:0] DQM_n,
    output reg dtack
    );

`include "globalparams.vh"

`define cmd(ARG) \
{RAS_n, CAS_n, WE_n} <= ARG;

localparam tRP = 2;
localparam tRCD = 2;
localparam tRFC = 4;
localparam CAS_LATENCY = 3'd2;

// RAS CAS WE
localparam cmd_nop             = 3'b111,
           cmd_active          = 3'b011,
           cmd_read            = 3'b101,
           cmd_write           = 3'b100,
           cmd_burst_terminate = 3'b110,
           cmd_precharge       = 3'b010,
           cmd_auto_refresh    = 3'b001,
           cmd_load_mode_reg   = 3'b000;


localparam mode_register = {
  3'b0,        // M10-12 - Reserved
  1'b1,        // M9     - No burst mode, Single access
  2'b0,        // M8-7   - Standard operation
  CAS_LATENCY, // M6-4   - CAS Latency 
  1'b0,        // M3     - Burst type
  3'b0         // M2-0   - Burst length
};


reg [3:0] refresh_timer;
reg [1:0] refresh_request;
reg refreshing;

wire refreshreset = !refreshing & RESET_n;

// Refresh roughly every 7.1uS / 8192 refreshes in 58ms
always @(posedge ECLK or negedge refreshreset) begin
  if (!refreshreset) begin
    refresh_timer <= 4'h4;
  end else begin
    if (refresh_timer > 0) begin
      refresh_timer <= refresh_timer - 1;
    end
  end
end

always @(posedge CLK or negedge RESET_n) begin
  if (!RESET_n) begin
    refresh_request <= 0;
  end else begin
    refresh_request <= {refresh_request[0], refresh_timer == 0};
  end
end

localparam init_poweron        = 4'b0000,
           init_precharge      = init_poweron + 1,
           init_precharge_wait = init_precharge + 1,
           init_load_mode      = init_precharge_wait + 1,
           start_refresh       = init_load_mode + 1,
           refresh_wait        = start_refresh + 1,
           idle                = refresh_wait + 1,
           active              = idle + 1,
           active_wait         = active + 1,
           data_read           = active_wait + 1,
           data_write          = data_read + 1,
           data_hold           = data_write + 1,
           precharge_wait      = data_hold + 1;

(* fsm_encoding = "compact" *) reg [3:0] ram_state;

reg init_refreshed;
reg init_done;
reg [1:0] timer_tRFC;

always @(posedge CLK or negedge RESET_n) begin
  if (!RESET_n) begin
    ram_state      <= init_poweron;
    init_refreshed <= 0;
    init_done      <= 0;
    dtack          <= 0;
    CS_n           <= 2'b11;
    CKE            <= 1;
    DQM_n          <= 4'b1111;
  end else begin
    case (ram_state)

      // Showtime!
      //
      init_poweron:
        begin
          `cmd(cmd_nop)
          CS_n[1:0] <= 2'b00;
          ram_state <= init_precharge;
        end
      
      // Init precharge
      //
      init_precharge:
        begin
          `cmd(cmd_precharge)
          MADDR[10] <= 1'b1; // Precharge all banks
          ram_state <= init_precharge_wait;
        end
      
      // Init precharge wait
      //
      // Wait for precharge to complete
      init_precharge_wait:
        begin
          `cmd(cmd_nop)
          ram_state <= start_refresh;
        end

      // Load mode register
      //
      init_load_mode:
        begin
          `cmd(cmd_load_mode_reg)
          init_done   <= 1;
          MADDR[12:0] <= mode_register;
          ram_state   <= precharge_wait;
        end

      // Refresh
      //
      // Start auto-refresh
      start_refresh:
        begin
          `cmd(cmd_auto_refresh)
          timer_tRFC <= 2'b11;
          refreshing <= 1;
          CS_n       <= 2'b00; // Refresh all chips
          ram_state  <= refresh_wait;
        end
      
      // Refresh wait
      //
      // Wait for refresh to finish
      // During RAM initialization it will refresh twice then go to load the mode register
      refresh_wait:
        begin
          `cmd(cmd_nop)
          if (timer_tRFC > 0) begin
            timer_tRFC <= timer_tRFC - 1;
            ram_state  <= refresh_wait;
          end else begin
            if (!init_done) begin
              if (init_refreshed) begin
                // If we just finished the second init refresh go load the mode register
                ram_state      <= init_load_mode;
              end else begin
                // Do a second init refresh
                ram_state      <= start_refresh;
                init_refreshed <= 1;
              end
            end else begin
              ram_state <= idle;
            end
          end
        end

      // Idle
      //
      // Refresh has priority over memory access
      idle:
        begin
          `cmd(cmd_nop)
          refreshing <= 0;
          DQM_n <= 4'b1111;
          CS_n  <= 2'b11;
          if (refresh_request[1]) begin
            ram_state <= start_refresh;
          end else if (ram_cycle && (z3_state == Z3_START || z3_state == Z3_DATA)) begin
            ram_state <= active;
          end else begin
            ram_state <= idle;
          end
        end

      // Active
      //
      // Activate the row/bank
      active:
        begin
          `cmd(cmd_active)
          ram_state   <= active_wait;
          MADDR[12:0] <= ADDR[23:11];
          BA[1:0]     <= ADDR[25:24];
          CS_n[1:0]   <= {ADDR[26],~ADDR[26]};
        end

      // Wait
      //
      // Wait for tRCD and also wait until we see data strobes before committing writes
      active_wait:
        begin
          `cmd(cmd_nop)
          if (z3_state == Z3_DATA) begin
            // dtack <= 1;
            if (RW) begin
              ram_state <= data_read;
            end else begin
              dtack <= 1;
              ram_state <= data_write;
            end
          end else begin
            ram_state <= active_wait;
          end
        end

      // Read
      //
      data_read:
        begin
          `cmd(cmd_read)
          // Uses A27 as MA9 so that memory is mirrored above 128MB when using 4x32MB chips
          // Kickstart will detect the mirror and add 128MB to the free pool rather than 256MB
          // This allows for the board to be assembled with 128MB or 256MB without needing separate firmware.
          MADDR[12:0] <= {3'b001,ADDR[27], ADDR[10:2]};
          // Reads must return a full long regardless of DS (Zorro III Bus Specifications pg 3-3)
          DQM_n[3:0]  <= 4'b0000;
          ram_state   <= data_hold;
        end
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

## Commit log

2022-06-07 Remove burst stuff
    Burst feature not working properly and probably not worth the pain
    [sdram.v]
2022-06-11 Update Schematic
2022-06-13 Drive RAM and Autoconfig cycles with Z3 State machine
    Previously ram_cycle would latch at FCSn asserted and not be cleared until another FCSn assertion happened
    This caused issues because FCS_n_sync would lead ram_cycle_sync by 1 clock and this caused false memory cycles to start because ram_cycle_sync would still be true when it shouldn't be.
    [sdram.v]
2022-06-20 README: fix digikey link for resistor networks
2022-07-10 Public release
    Rev 1A - remove TP1/TP2 and make the board slightly narrower
    [GottaGoFaSDZ3-B_Cu.gbr, GottaGoFaSDZ3-B_Mask.gbr, GottaGoFaSDZ3-B_Paste.gbr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]
2022-07-21 Correct R2 value and memory size in README (thanks to Kavanoz)
    [GottaGoFaSDZ3.kicad_pcb, GottaGoFaSDZ3.kicad_sch]
2022-08-31 Makefile tweaks
    * CPLDFIT: set unused outputs (TP1,TP2) to GND
    * Tweak flash target so that it will use the .jed in the Binaries directory
2023-04-15 Switch from Prototype Autoconfig ID to OAHR Manufacturer
2023-06-28 Remove dirty speed hack
    Previously the board would assert DTACK very early on reads for a speed
    boost...
    This usually isn't a problem because Buster is slow to notice but sometimes causes issues for the A4091
    Thanks goes to dorken @ a1k.org for pointing this out
    [sdram.v]
2024-09-27 Tweak DTACK
    On reads, DTACK will now come out 3 clocks after the READ command to the RAM
    With a CAS latency of 2, the read data will be valid at READ+2
    The A4091 latches data as soon as DTACK is seen, so this delay was needed to make sure the A4091 correctly latches data from GottaGoFaZt3r
    [sdram.v]
2025-02-02 Add reverse install protection
    [GottaGoFaSDZ3-B_Cu.gbl, GottaGoFaSDZ3-B_Cu.gbr, GottaGoFaSDZ3-B_Mask.gbr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]
